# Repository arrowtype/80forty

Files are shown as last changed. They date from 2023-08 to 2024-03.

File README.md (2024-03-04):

# 80forty Keyboard

The utility of an 80% keyboard in a 40% form factor.

Inspired by the design of the [OP-1 Synthesizer](https://teenage.engineering/store/op-1-field/), the explorative spirit of the 40% & 30% keyboard community (especially boards like ChonkyKong, CutiePie, and Ortho Cajal), and the tactile reference points and minimized finger-travel of many split, ergonomic keyboards. The 80forty was partly motivated by the appearance of [Deadline Studio DOYS keycaps](https://deadline.space/products/doys-keycaps), but it works with any MX-compatible keycaps.

The 80forty has a layout that is ortholinear and minimal, but still retains the keys that are helpful for everyday computing and specialized tasks like graphic design applications (i.e. arrow keys, bottom mod keys, and outer columns allowing for e.g. dedicated shift and backspace keys). It also allows either a knob or a 2x2 macropad above the arrow keys.

Supports low-profile KS33 switches (with hotswap sockets) as well as MX switches (soldered/mill-maxed).

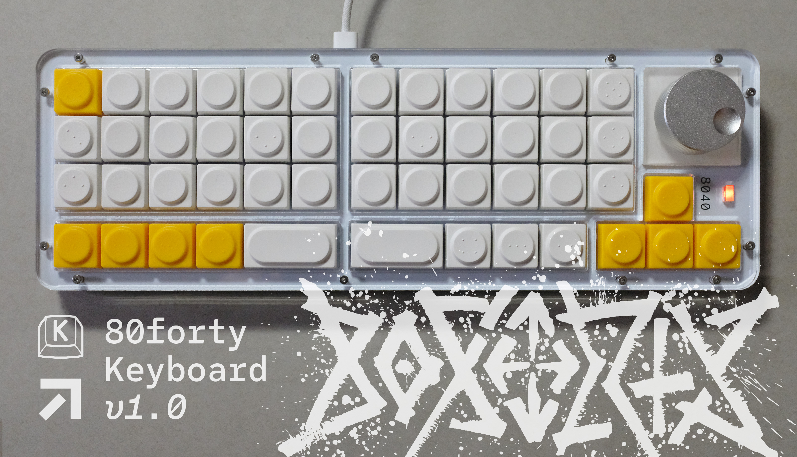
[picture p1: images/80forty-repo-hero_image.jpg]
Overview of 80forty with the v1 stacked acrylic case


## V1 Case Designs

Version 1 uses either a stacked acrylic or ”skeleton” FR4 plate design.

While the PCB supports either KS33 or MX switches, the current case designs have only been settled for the KS33 switches. MX switches require more space, and would likely require larger middle case layers.

### Stacked Acrylic Case

This case uses the standard FR4 top plate of the 80forty, and sandwiches it in a few layers of 5mm, lasercut acrylic.

Side view of 80forty keyboard with stacked acrylic case

Bottom view of 80forty keyboard with stacked acrylic case

### Skeleton FR4 Case

This case uses the standard FR4 top and bottom plates of the 80forty, with standoffs providing middle separation for the switches.

Close-up view of 80forty keyboard with skeleton FR4 case

Profile view of 80forty keyboard with skeleton FR4 case

Close-up bottom view of 80forty keyboard with skeleton FR4 case

## Configuration Options

Configurable with either 1 large knob or 4 macro keys.

80forty-knob

80forty-macro

## Keymaps

80forty is configurable in Vial, so the keymap can be whatever you want! However, here are two example layouts to show what might be common approaches to such a keyboard.

The 2-unit spacebars are intended to serve double duty: to input `Space` when tapped, or to shift to respective layers when held.

80forty-example-keymap-simpler

Vial/QMK also allow for “key combos.” So, for instance, it is possible to forgo a dedicated `Escape` key and instead assign this to `Tilde` + `Q`.

80forty-example-keymap

## Future Vision

The project was conceived to allow a sleek, low-profile, CNC aluminum case design. This is still a goal, but there is no current timeline for this version.

In the slightly nearer term, the intention is to prototype this case with 3D printing. If anyone out there is interested in creating this 3D case and contributing it to the project, let us know in the issues or in a pull request!

8040 Knob

8040 Macro

## Credits

Concept, layout, case design, and PCB graphics by Stephen Nixon / ArrowType.

Engineering, code, and PCB specifications and ordering by Noah Kiser / Kiser Designs.

## To be continued!

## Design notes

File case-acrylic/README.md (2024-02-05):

# 80forty Acrylic Case

TODO: 
- [ ] Sliiightly offset acrylic edges to exceed FR4 plate?
- [ ] Add list of hardware required
  - [ ] Also add this for the skeleton case
- [ ] Document tips for ordering acrylic case

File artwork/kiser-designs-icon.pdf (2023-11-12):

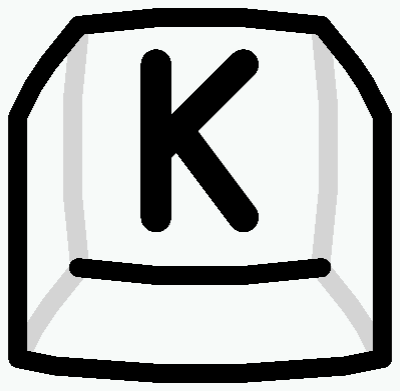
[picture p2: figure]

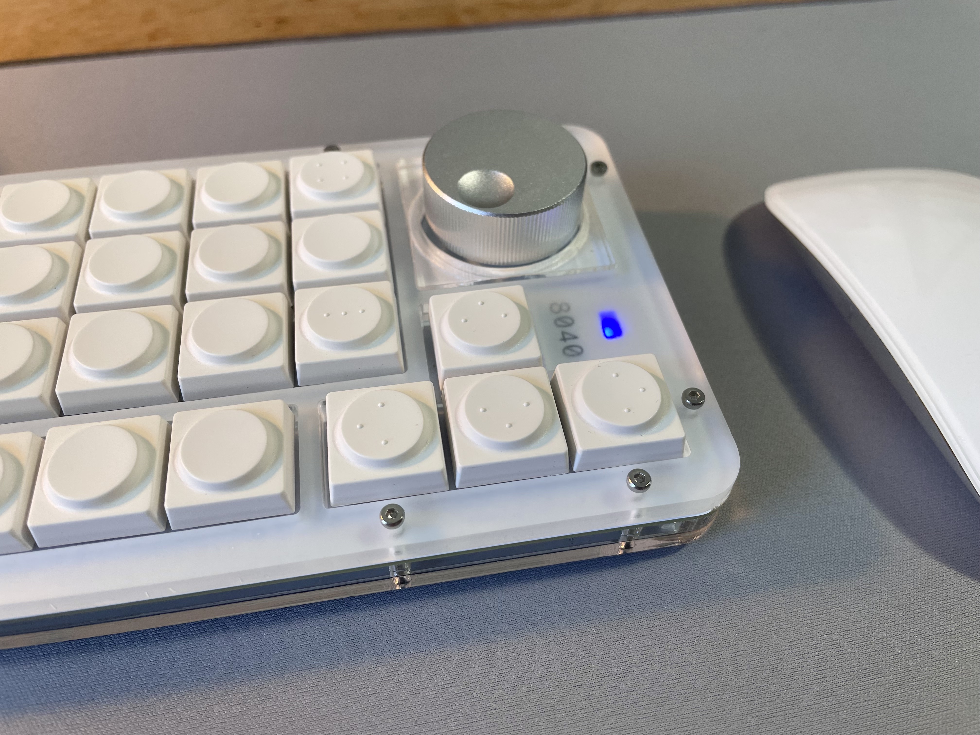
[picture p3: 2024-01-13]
images/80forty-keyboard-v1-detail.jpeg

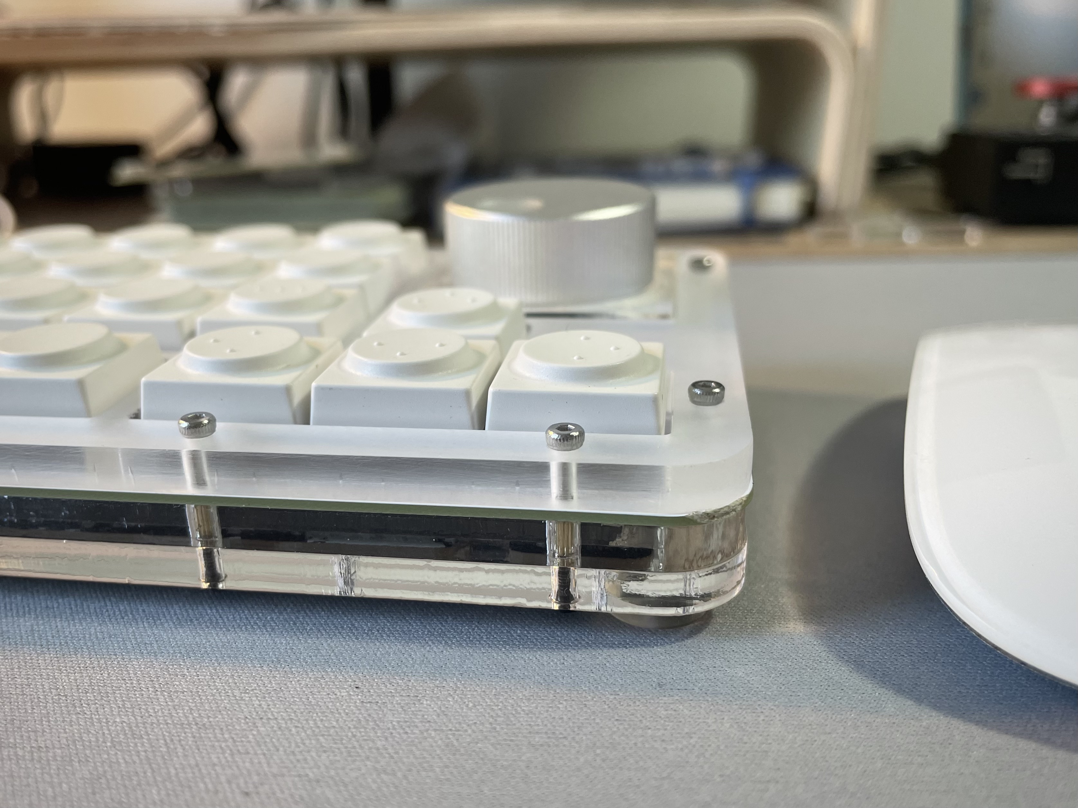
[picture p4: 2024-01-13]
images/80forty-keyboard-v1-side.jpeg

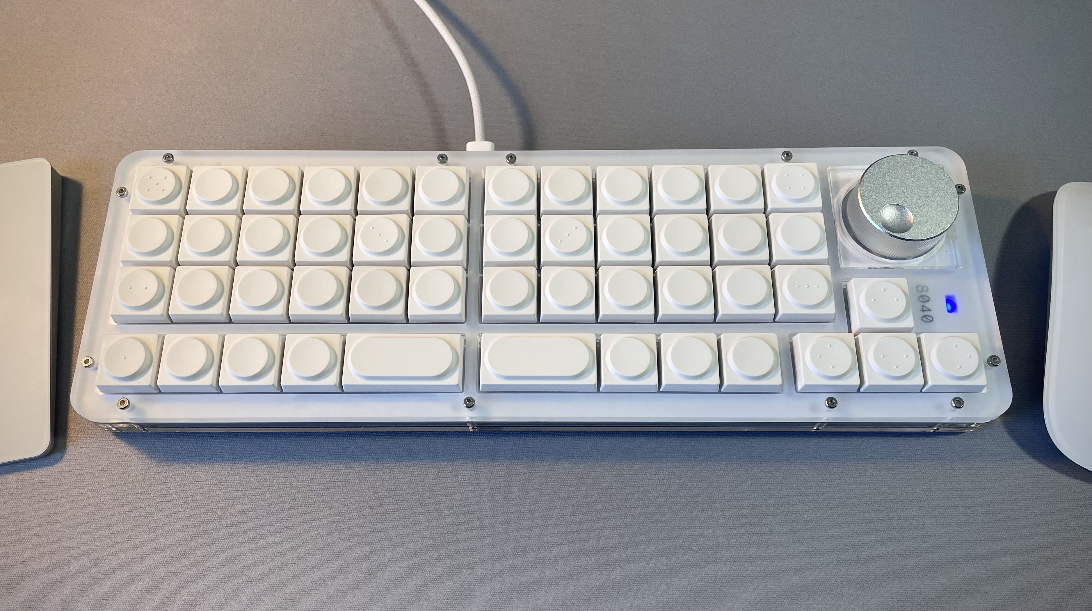
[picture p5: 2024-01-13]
images/80forty-keyboard-v1.jpeg

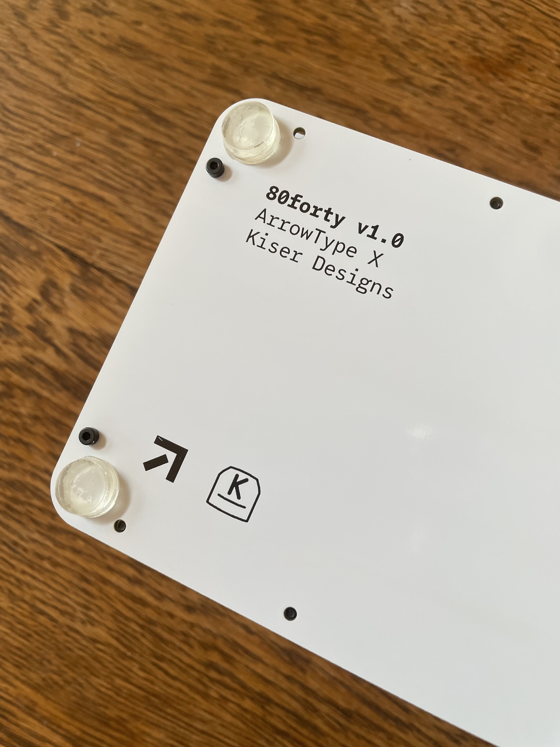
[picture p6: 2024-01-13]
images/80forty-keyboard-v1-skeleton-bottom.jpeg

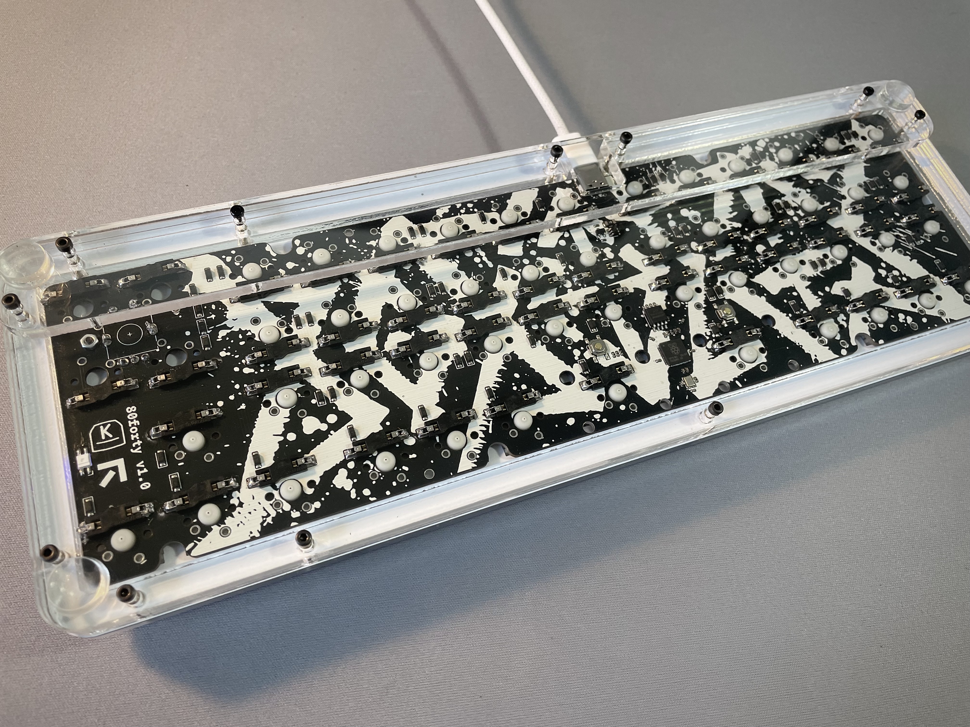
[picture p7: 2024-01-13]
images/80forty-keyboard-v1-bottom.jpeg

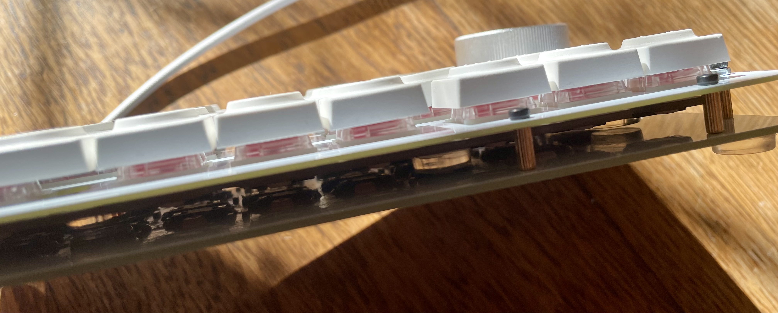
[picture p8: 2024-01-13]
images/80forty-keyboard-v1-skeleton-side.jpeg

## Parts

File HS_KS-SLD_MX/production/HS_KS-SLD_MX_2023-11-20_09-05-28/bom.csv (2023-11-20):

Designator | Footprint | Quantity | Value | LCSC Part #
C1, C2, C4, C5 | 402 | 4 | 1u | C52923
C10, C15, C3, C6, C7, C8, C9 | 402 | 7 | 100n | C1525
C12, C13 | 402 | 2 | 22p | C1562
C14 | 402 | 1 | 10u | C15525
D1, D10, D11, D12, D13, D14, D15, D16, D17, D18, D19, D2, D20, D21, D22, D23, D24, D25, D26, D27, D28, D29, D3, D30, D31, D32, D33, D34, D35, D36, D37, D38, D39, D4, D40, D41, D42, D43, D44, D45, D46, D47, D48, D49, D5, D50, D51, D52, D53, D6, D7, D8, D9 | D_SOD-123 | 53 | D_Small | C81598
F1 | 1206 | 1 | Fuse_Small | C883133
J1 | USB_C_Receptacle_HRO_TYPE-C-31-M-12 | 1 | USB_C_Receptacle_USB2.0 | C165948
LED1 | LED_6028R | 1 | SK6812MINI-E | C5149201
R1, R2, R3, R4, R6 | 402 | 5 | 5.1k | C25905
R5, R9 | 402 | 2 | 1k | C11702
R7, R8 | 402 | 2 | 27 | C25092
SWR1, SWR2 | SW_SPST_TL3342 | 2 | SW_SPST | C318884
U1 | SOT-23 | 1 | XC6206PxxxMR | C5446
U2 | SOT-23-6-routable | 1 | SRV05-4 | C85364
U3 | SOIC-8_5.23x5.23mm_P1.27mm | 1 | W25Q128JVS | C97521
U4 | QFN-56-1EP_7x7mm_P0.4mm_EP3.2x3.2mm | 1 | RP2040TR7 | C2040
Y1 | Crystal_SMD_3225-4Pin_3.2x2.5mm | 1 | Crystal_GND24_Small | C9002
 |  |  |  |  | s

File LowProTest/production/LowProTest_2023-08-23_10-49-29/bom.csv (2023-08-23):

Designator | Footprint | Quantity | Value | LCSC Part #
SW1_2, SW1 | gateron-ks-33 | 2 | SW_Push_45deg
SW2_2, SW2 | KS-33-HS | 2 | SW_Push_45deg
SW8_2, SW8 | SW_MX_HS_1u | 2 | SW_Push_45deg

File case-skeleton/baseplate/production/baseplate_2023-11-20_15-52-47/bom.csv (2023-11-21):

Designator | Footprint | Quantity | Value | LCSC Part #
_13, _12, _11, _10, _9, _8, _7, _6, _5, _4, _3, _2, |  | 13

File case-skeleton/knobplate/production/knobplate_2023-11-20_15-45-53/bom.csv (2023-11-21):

Designator | Footprint | Quantity | Value | LCSC Part #
_18, _17, _16, _15, _14, _13, _12, _11, _10, _9, _8, _7, _6, _5, _4, _3, _2, |  | 18

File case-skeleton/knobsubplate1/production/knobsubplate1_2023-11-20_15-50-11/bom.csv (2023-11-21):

Designator | Footprint | Quantity | Value | LCSC Part #
_4, _3, _2, |  | 4

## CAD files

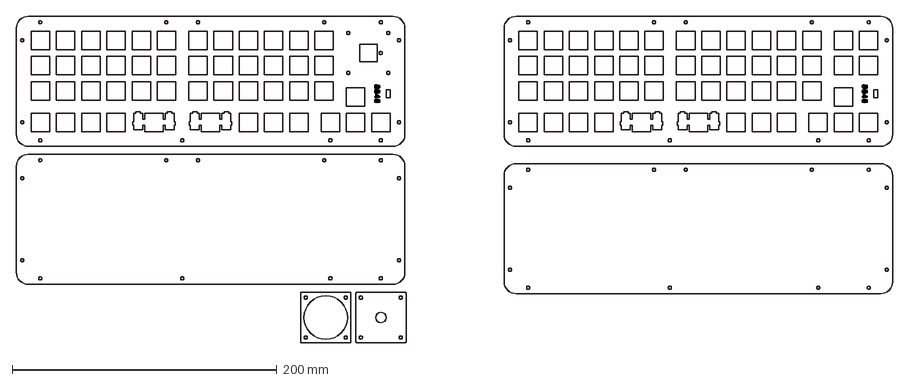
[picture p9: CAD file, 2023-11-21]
case-skeleton/80forty-plates_to_cut-2023_11_20.dxf
661.8 x 246.6 mm

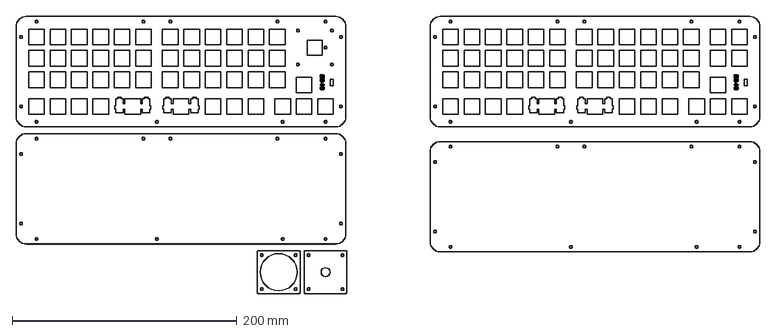
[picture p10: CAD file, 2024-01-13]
plates/80forty-plates_to_cut-2023_11_20.dxf
661.8 x 246.6 mm

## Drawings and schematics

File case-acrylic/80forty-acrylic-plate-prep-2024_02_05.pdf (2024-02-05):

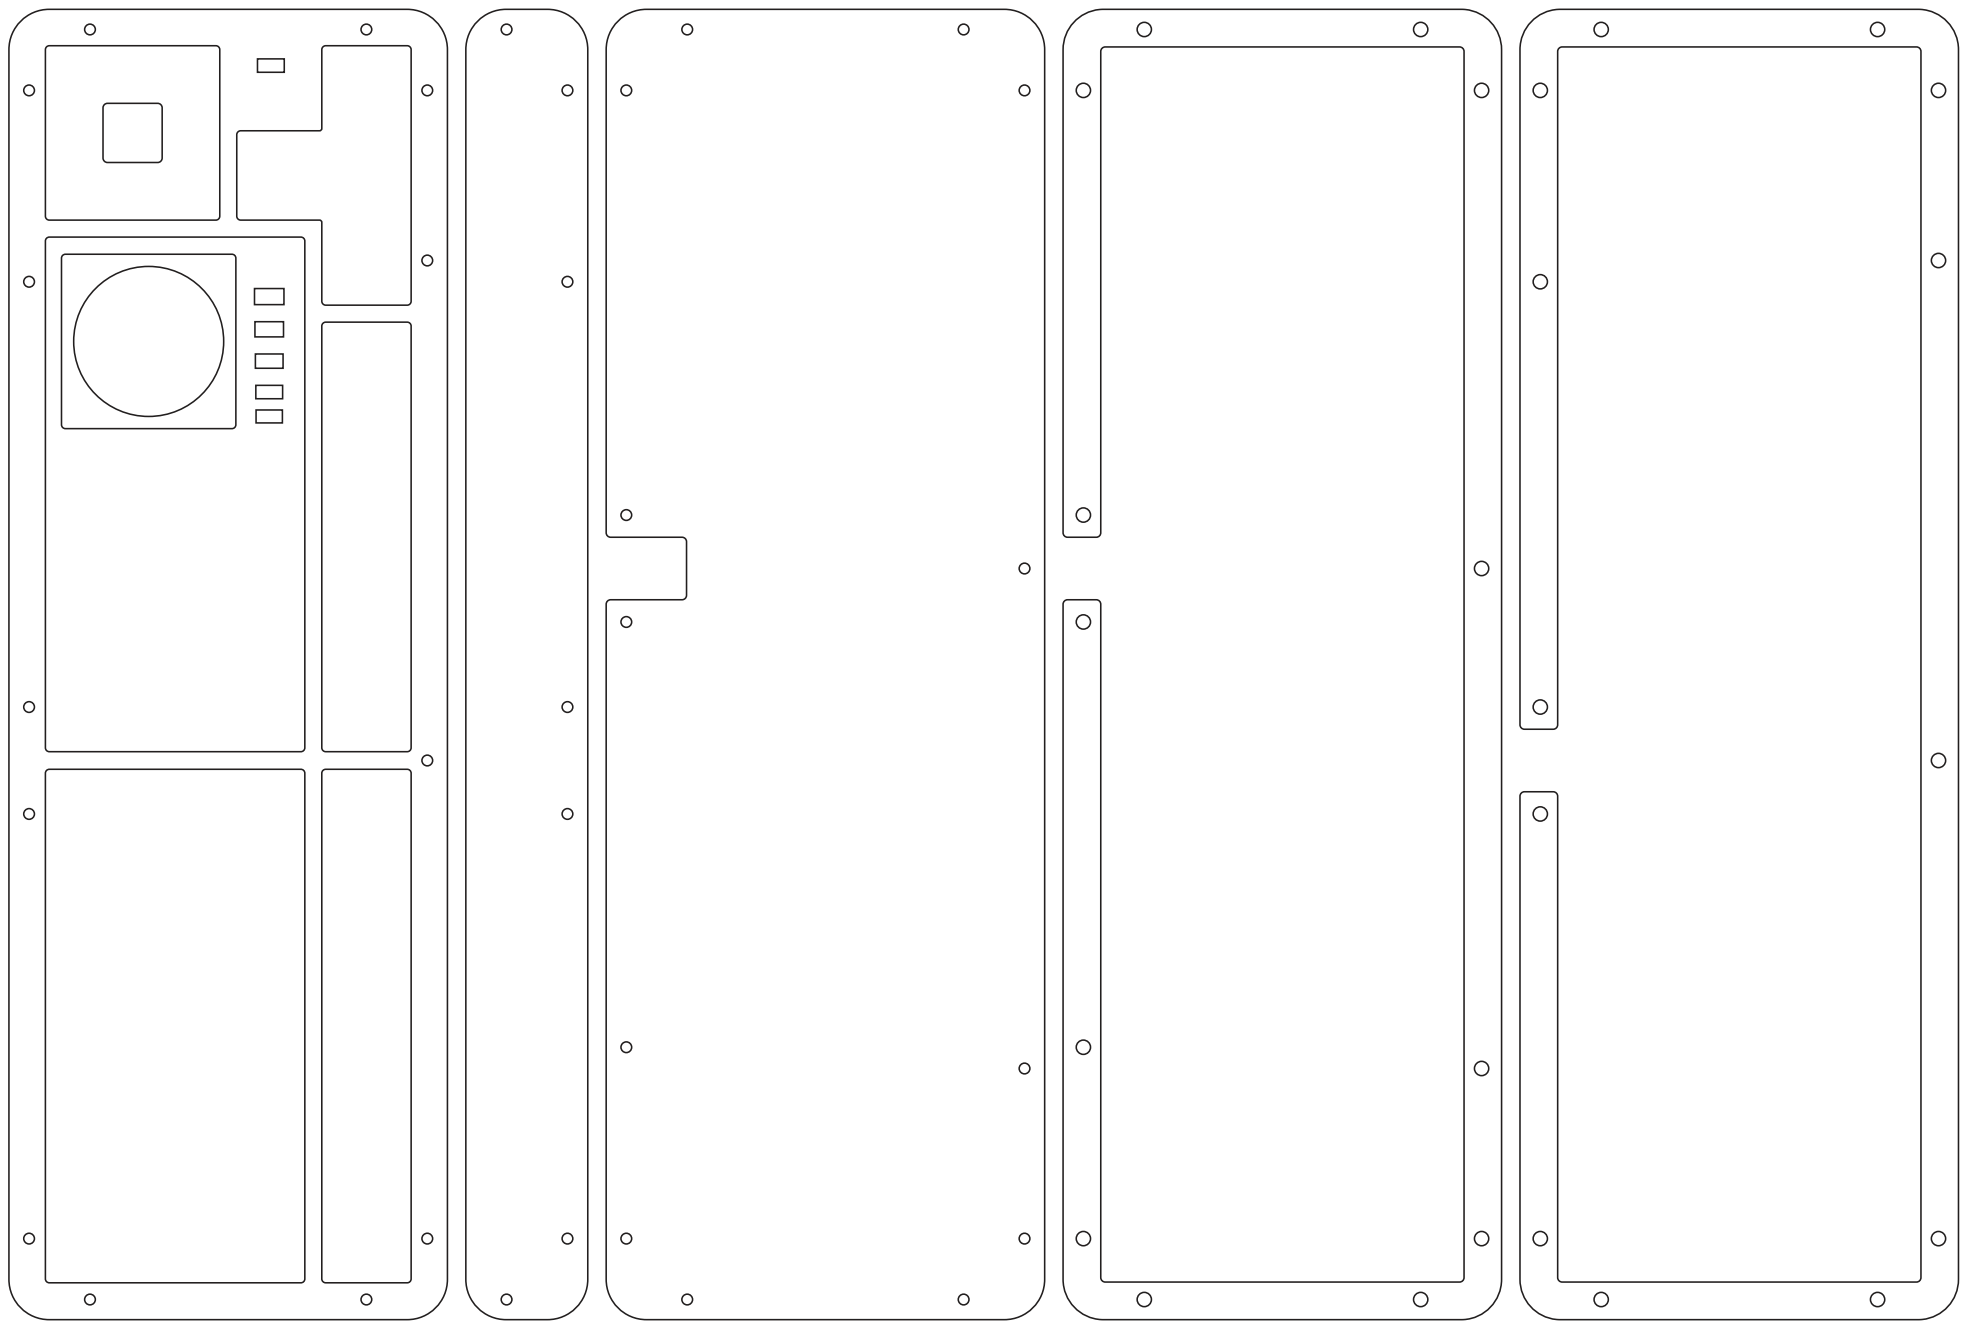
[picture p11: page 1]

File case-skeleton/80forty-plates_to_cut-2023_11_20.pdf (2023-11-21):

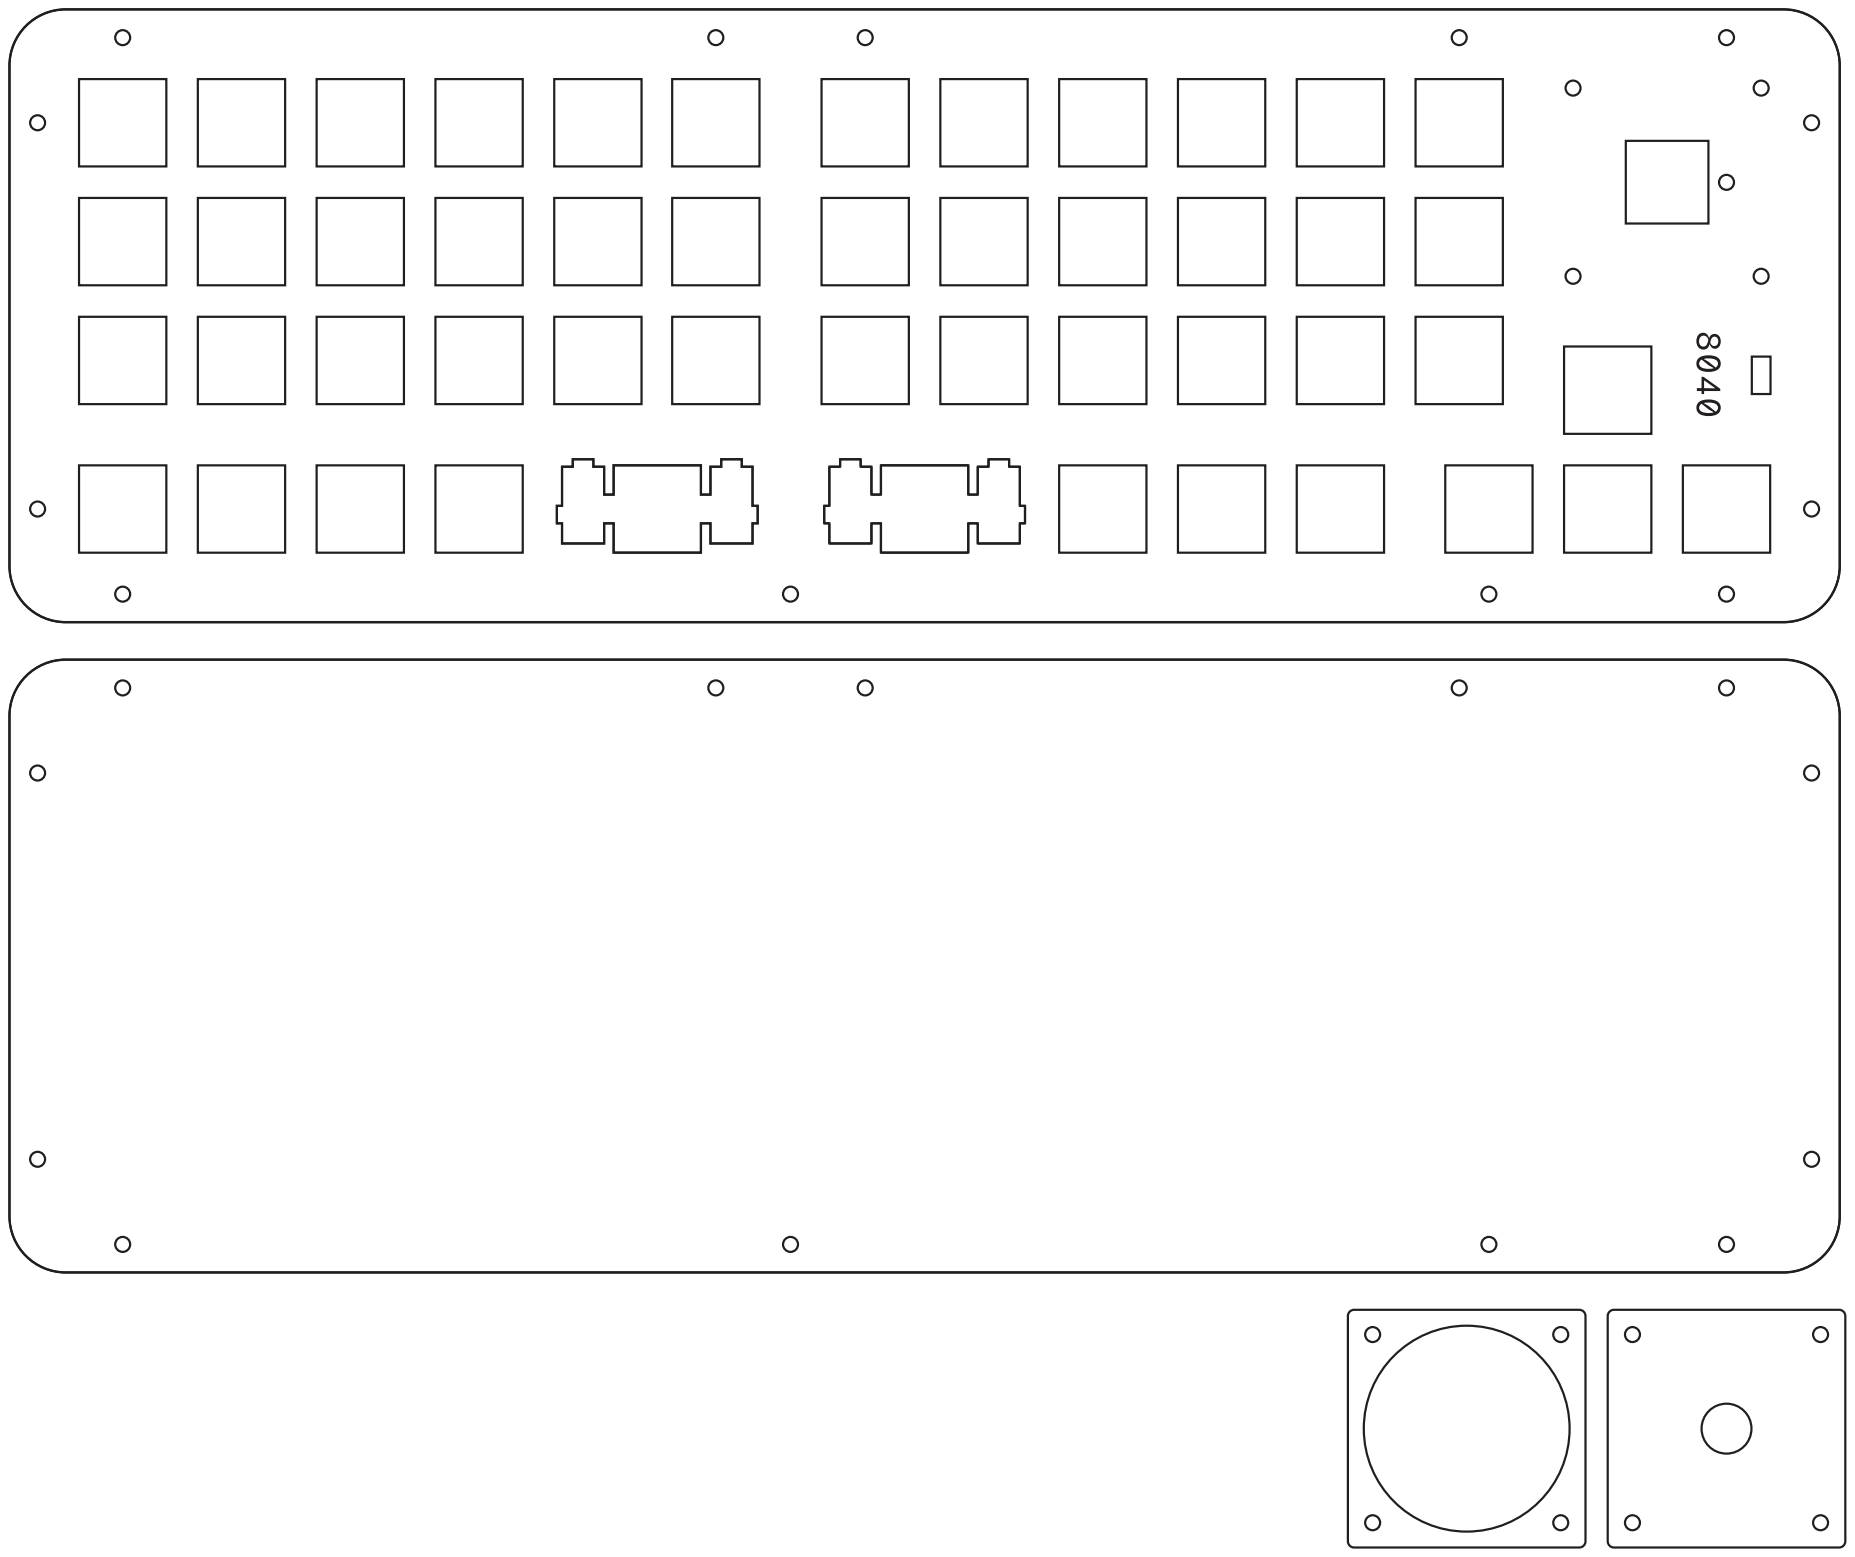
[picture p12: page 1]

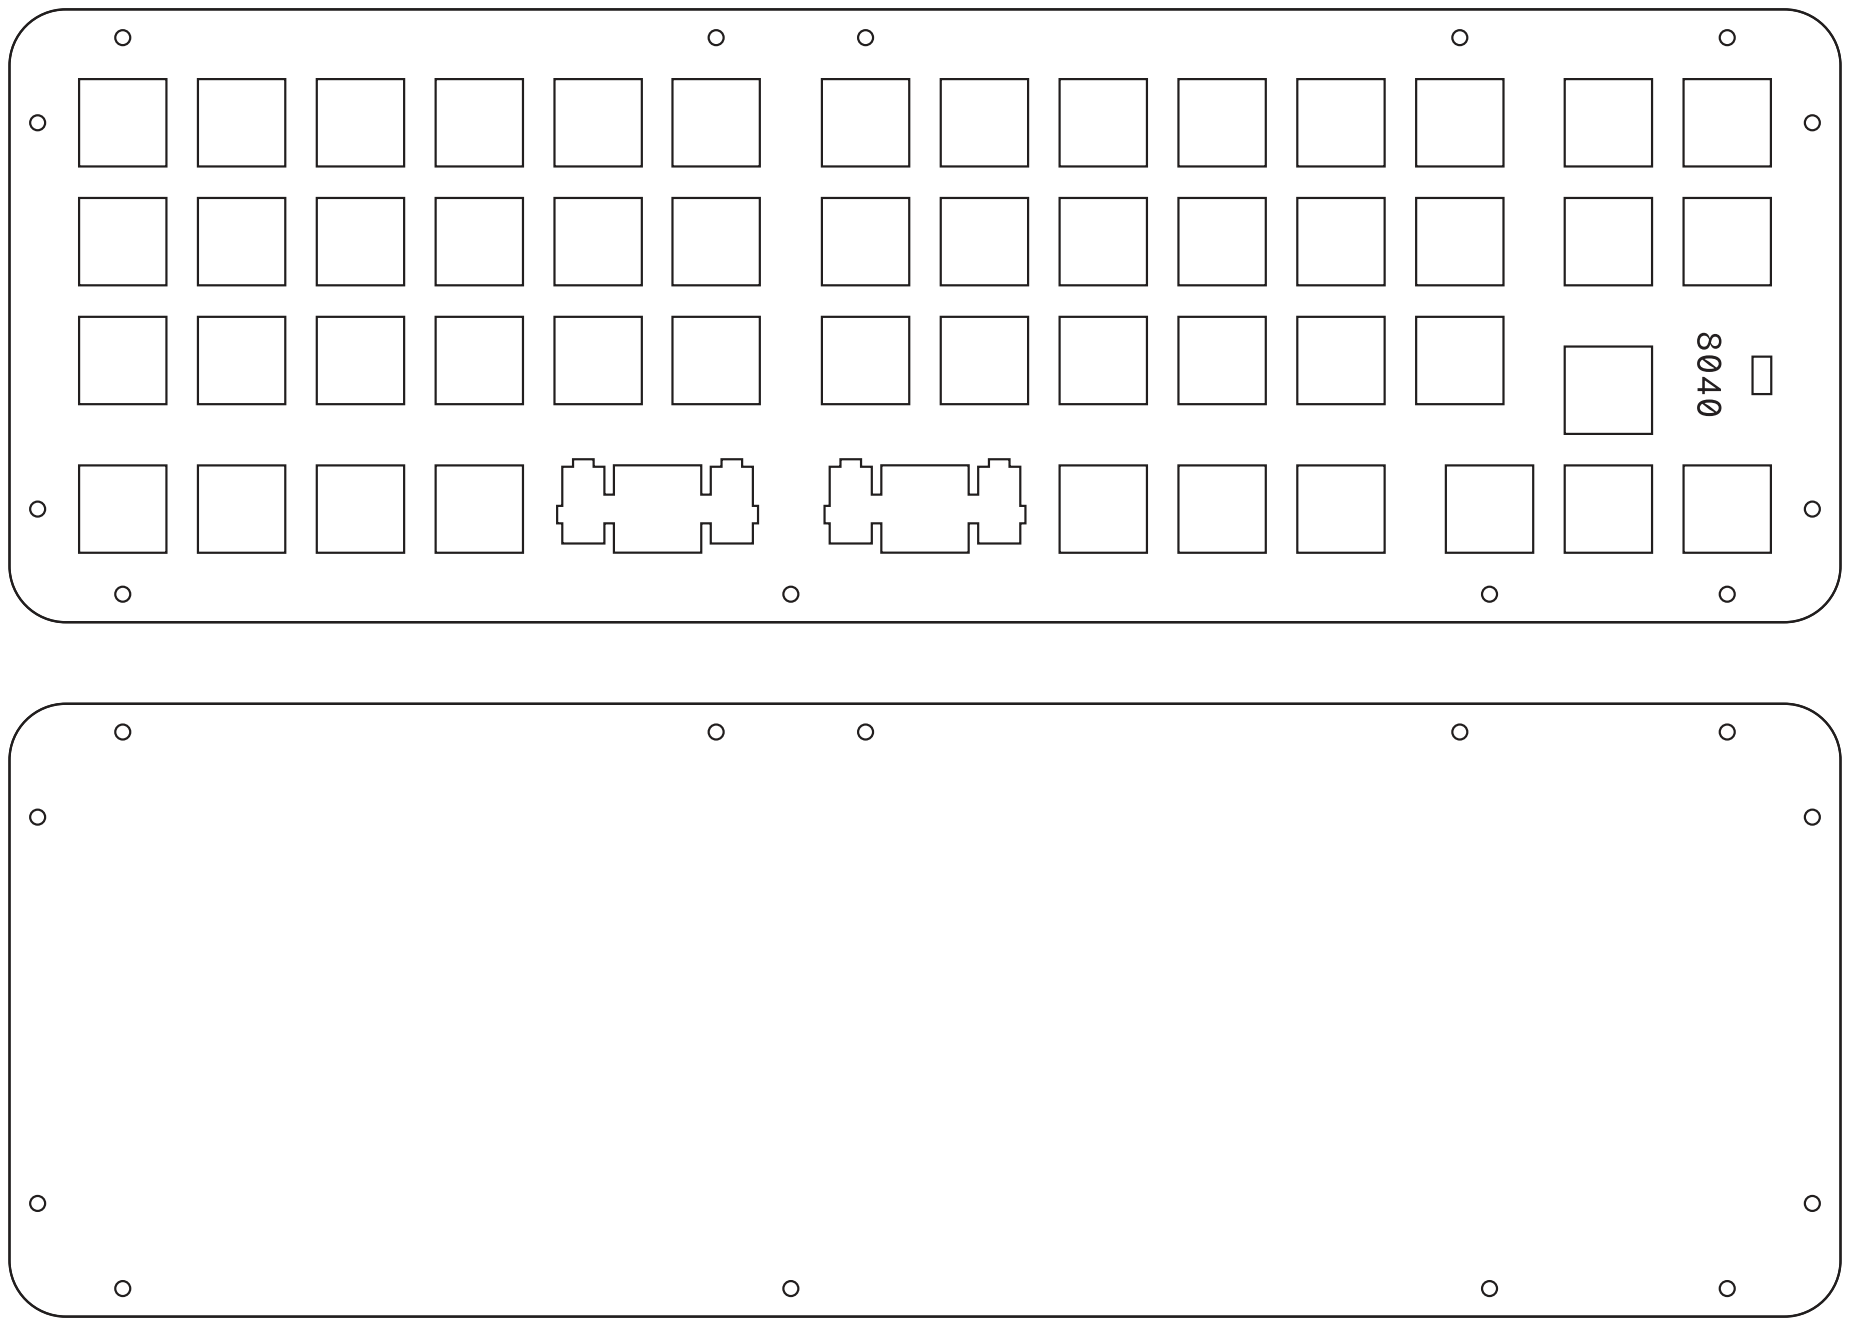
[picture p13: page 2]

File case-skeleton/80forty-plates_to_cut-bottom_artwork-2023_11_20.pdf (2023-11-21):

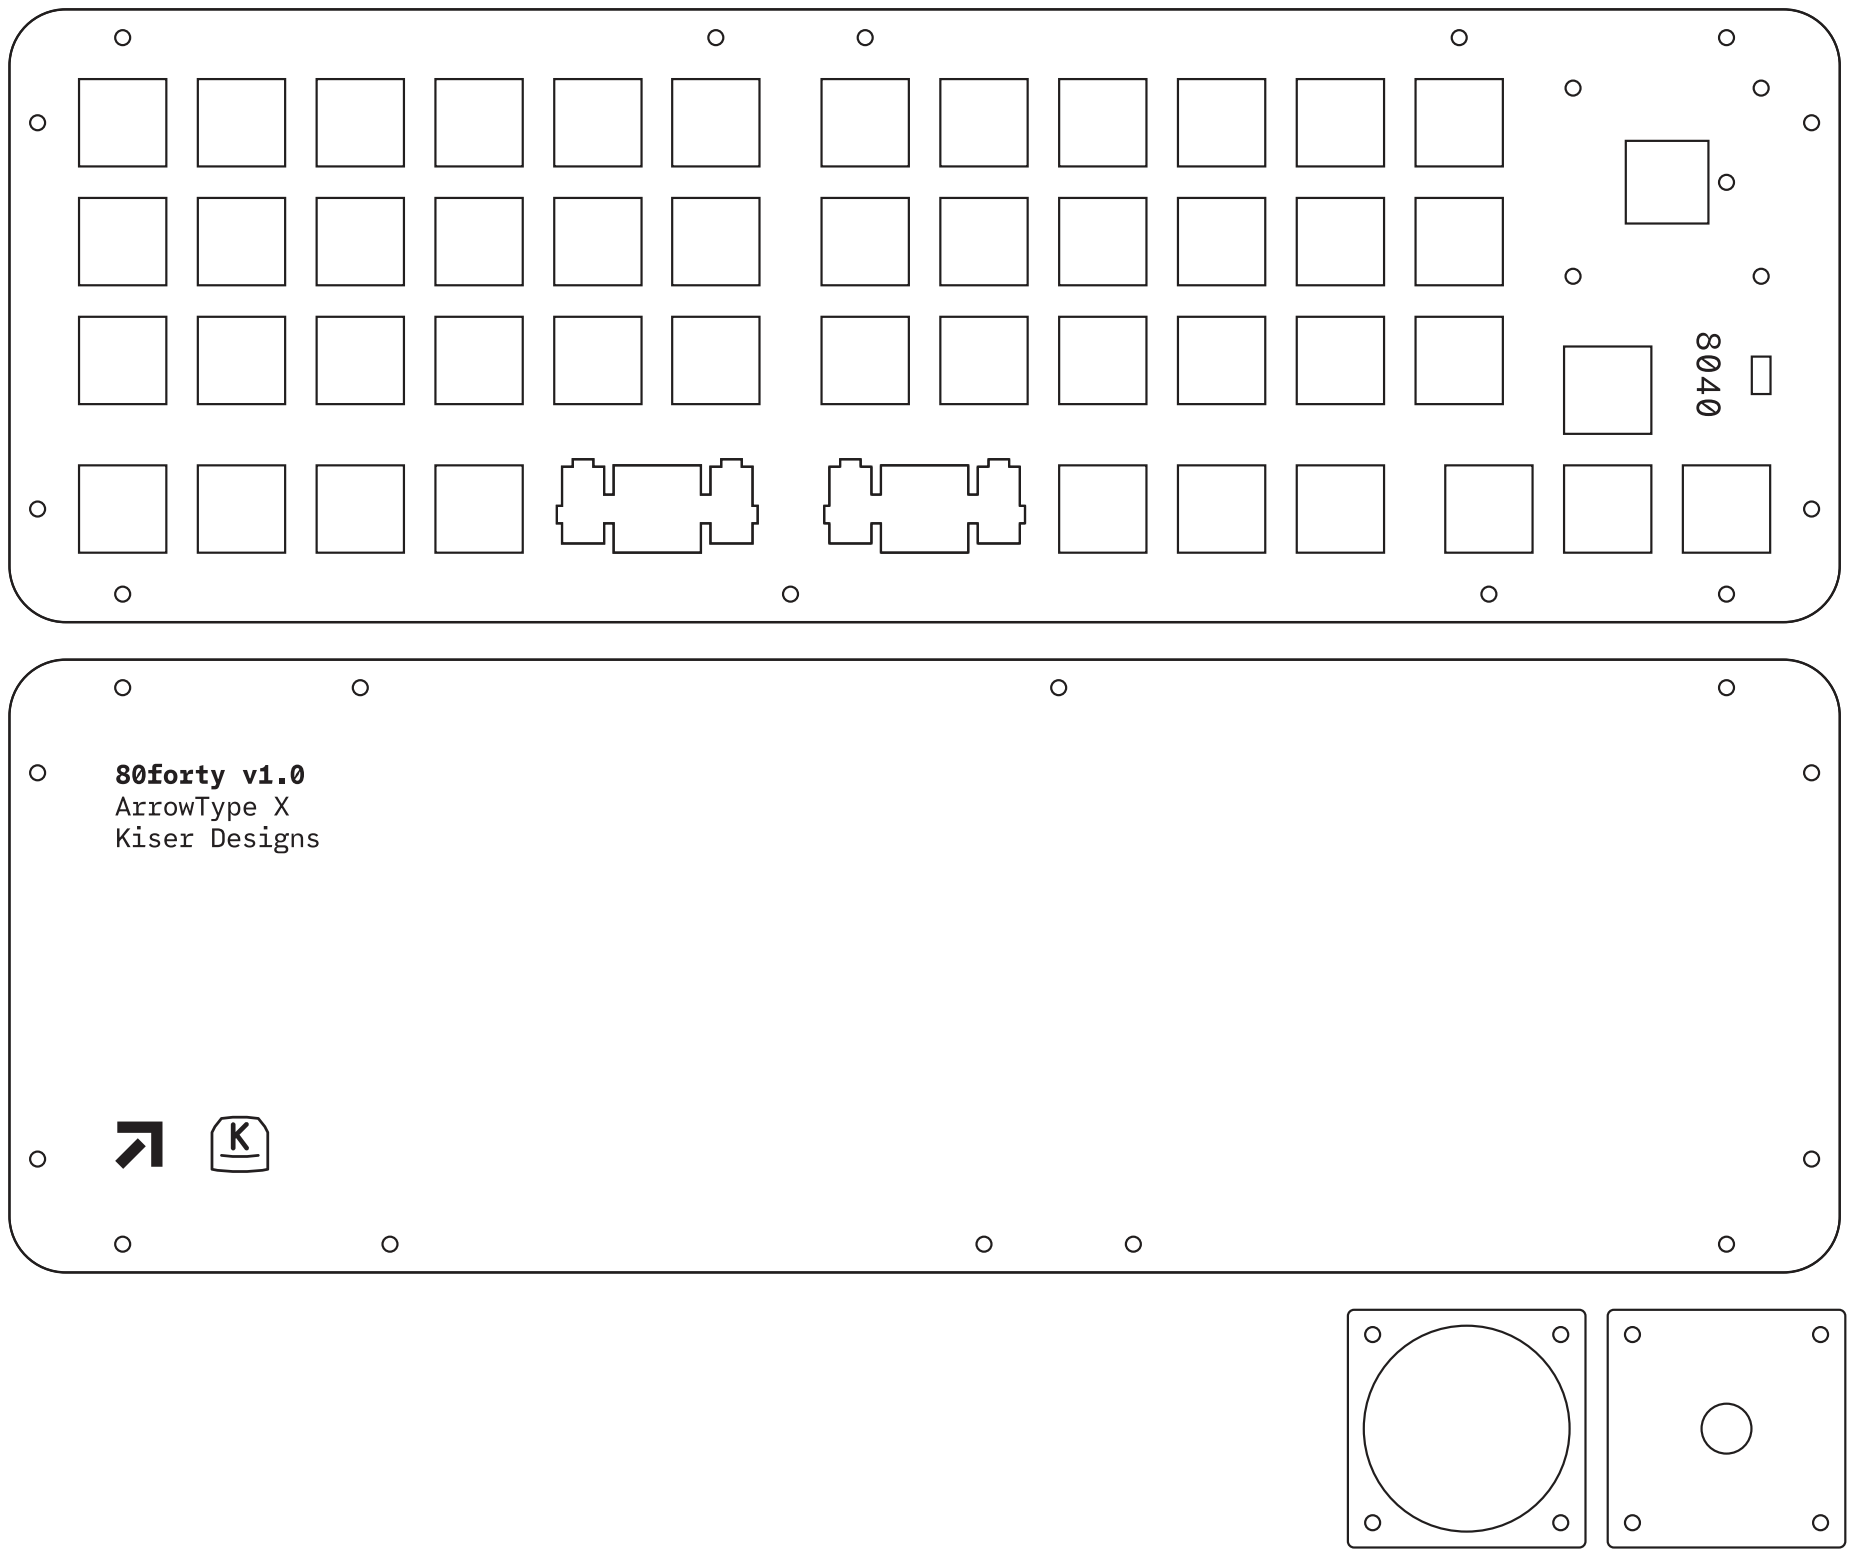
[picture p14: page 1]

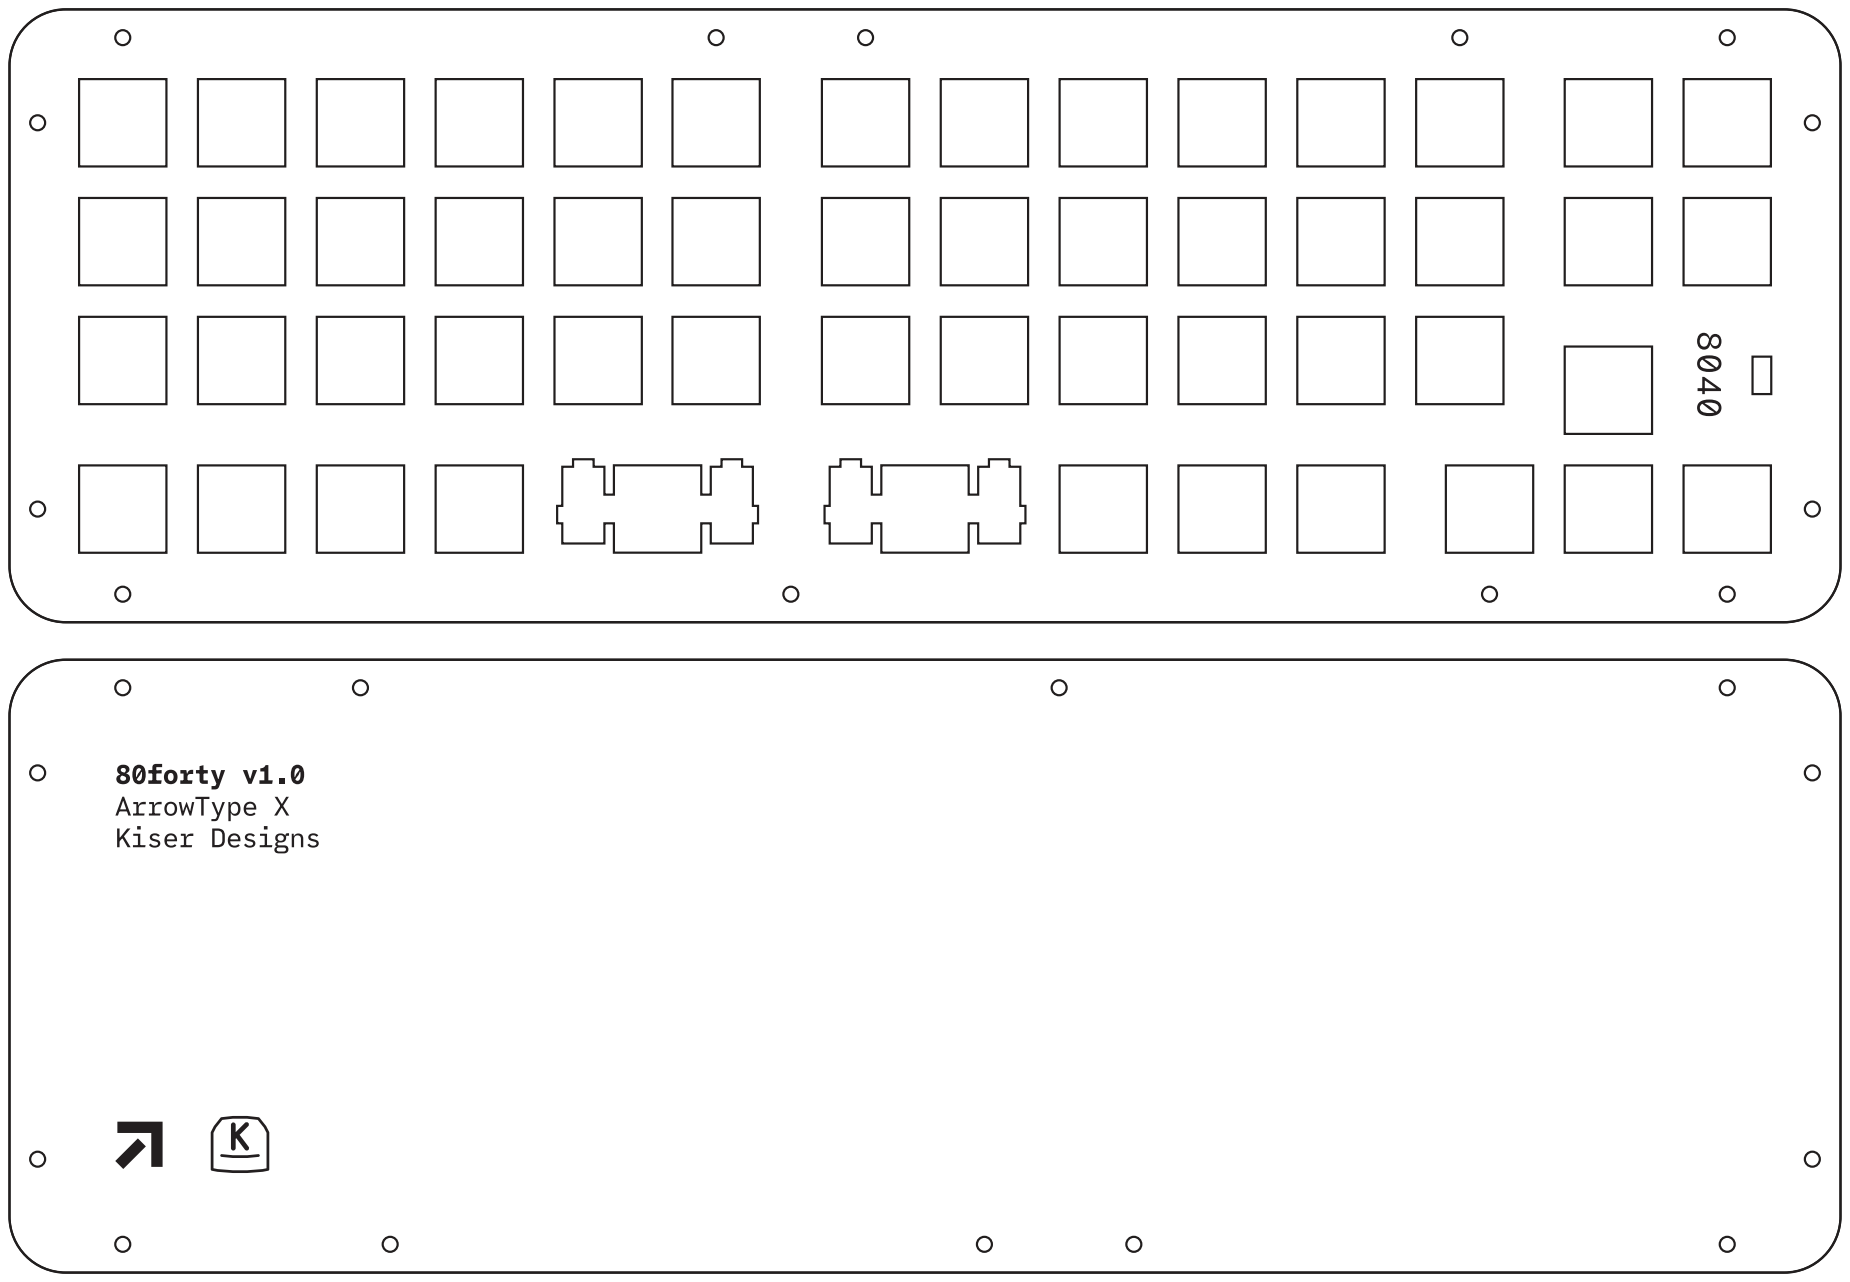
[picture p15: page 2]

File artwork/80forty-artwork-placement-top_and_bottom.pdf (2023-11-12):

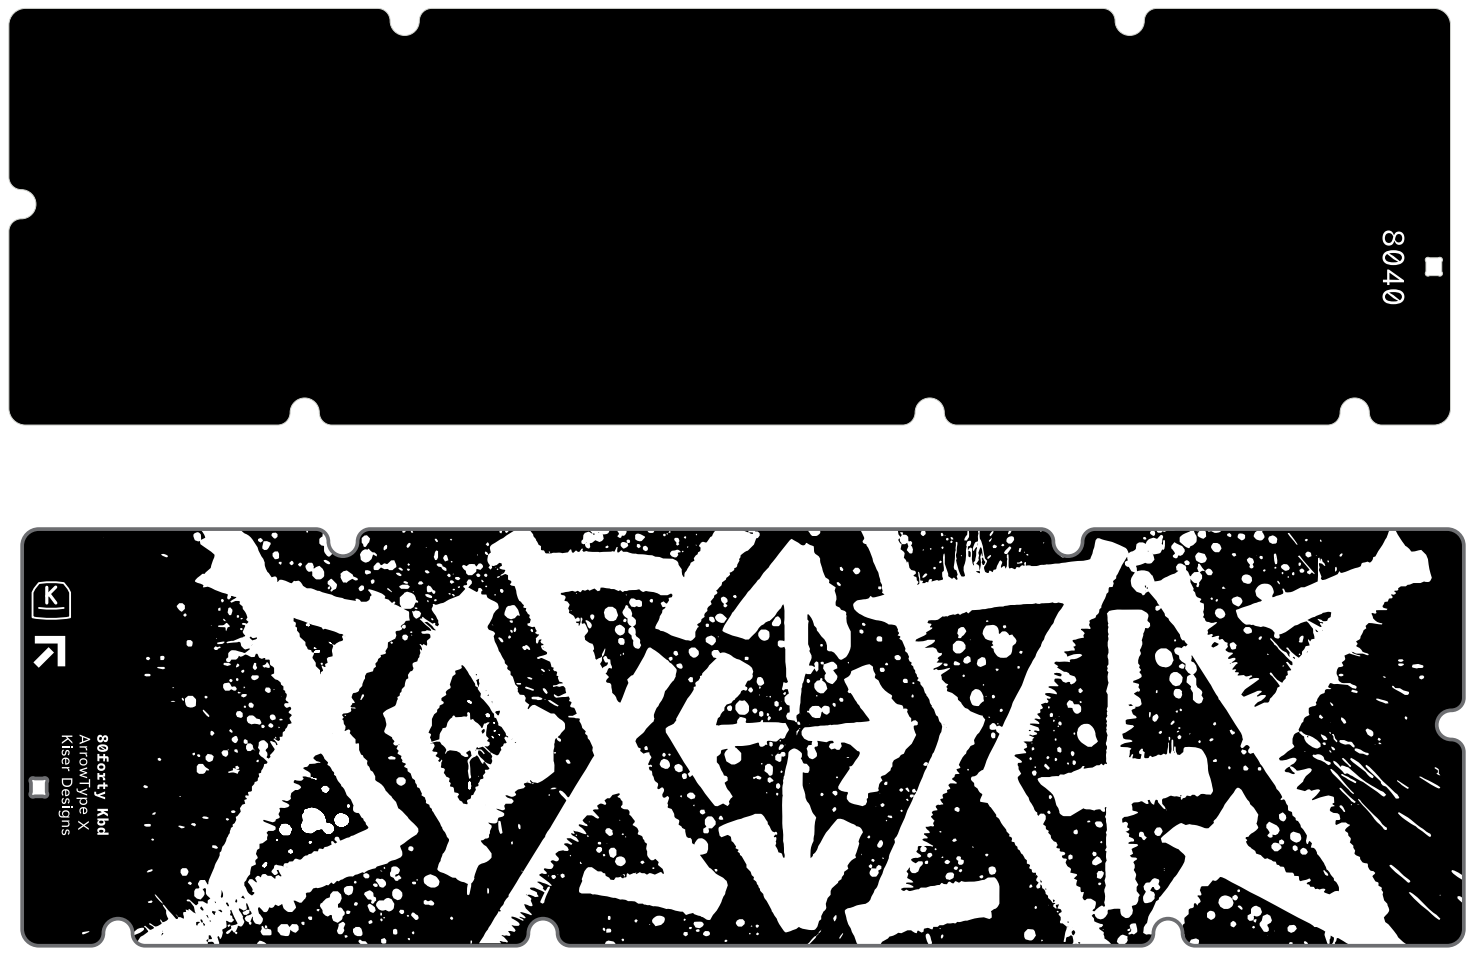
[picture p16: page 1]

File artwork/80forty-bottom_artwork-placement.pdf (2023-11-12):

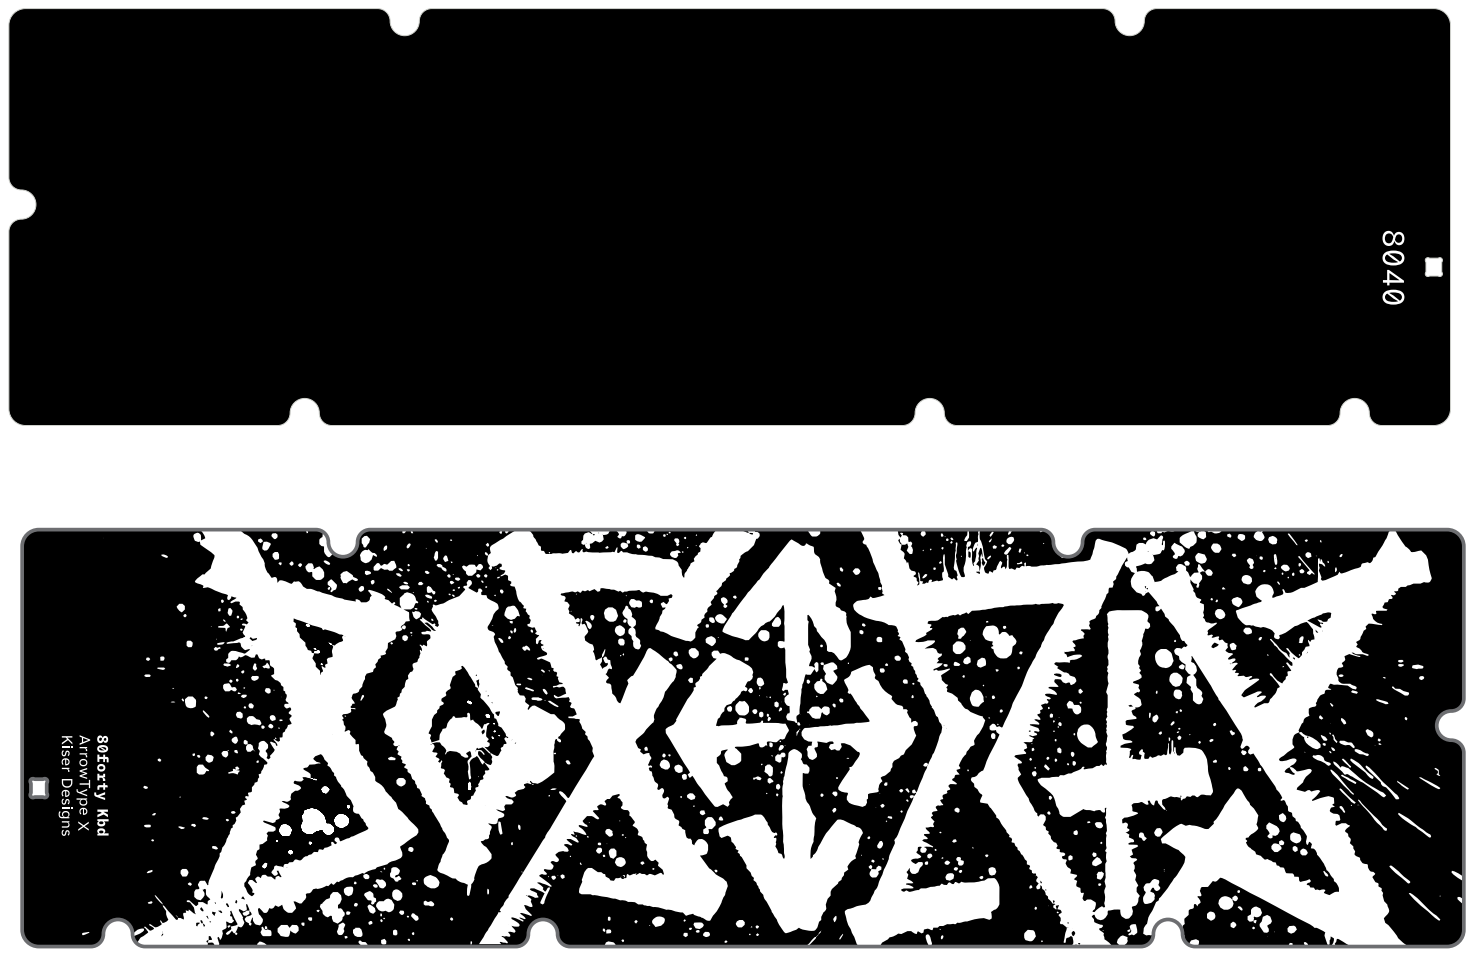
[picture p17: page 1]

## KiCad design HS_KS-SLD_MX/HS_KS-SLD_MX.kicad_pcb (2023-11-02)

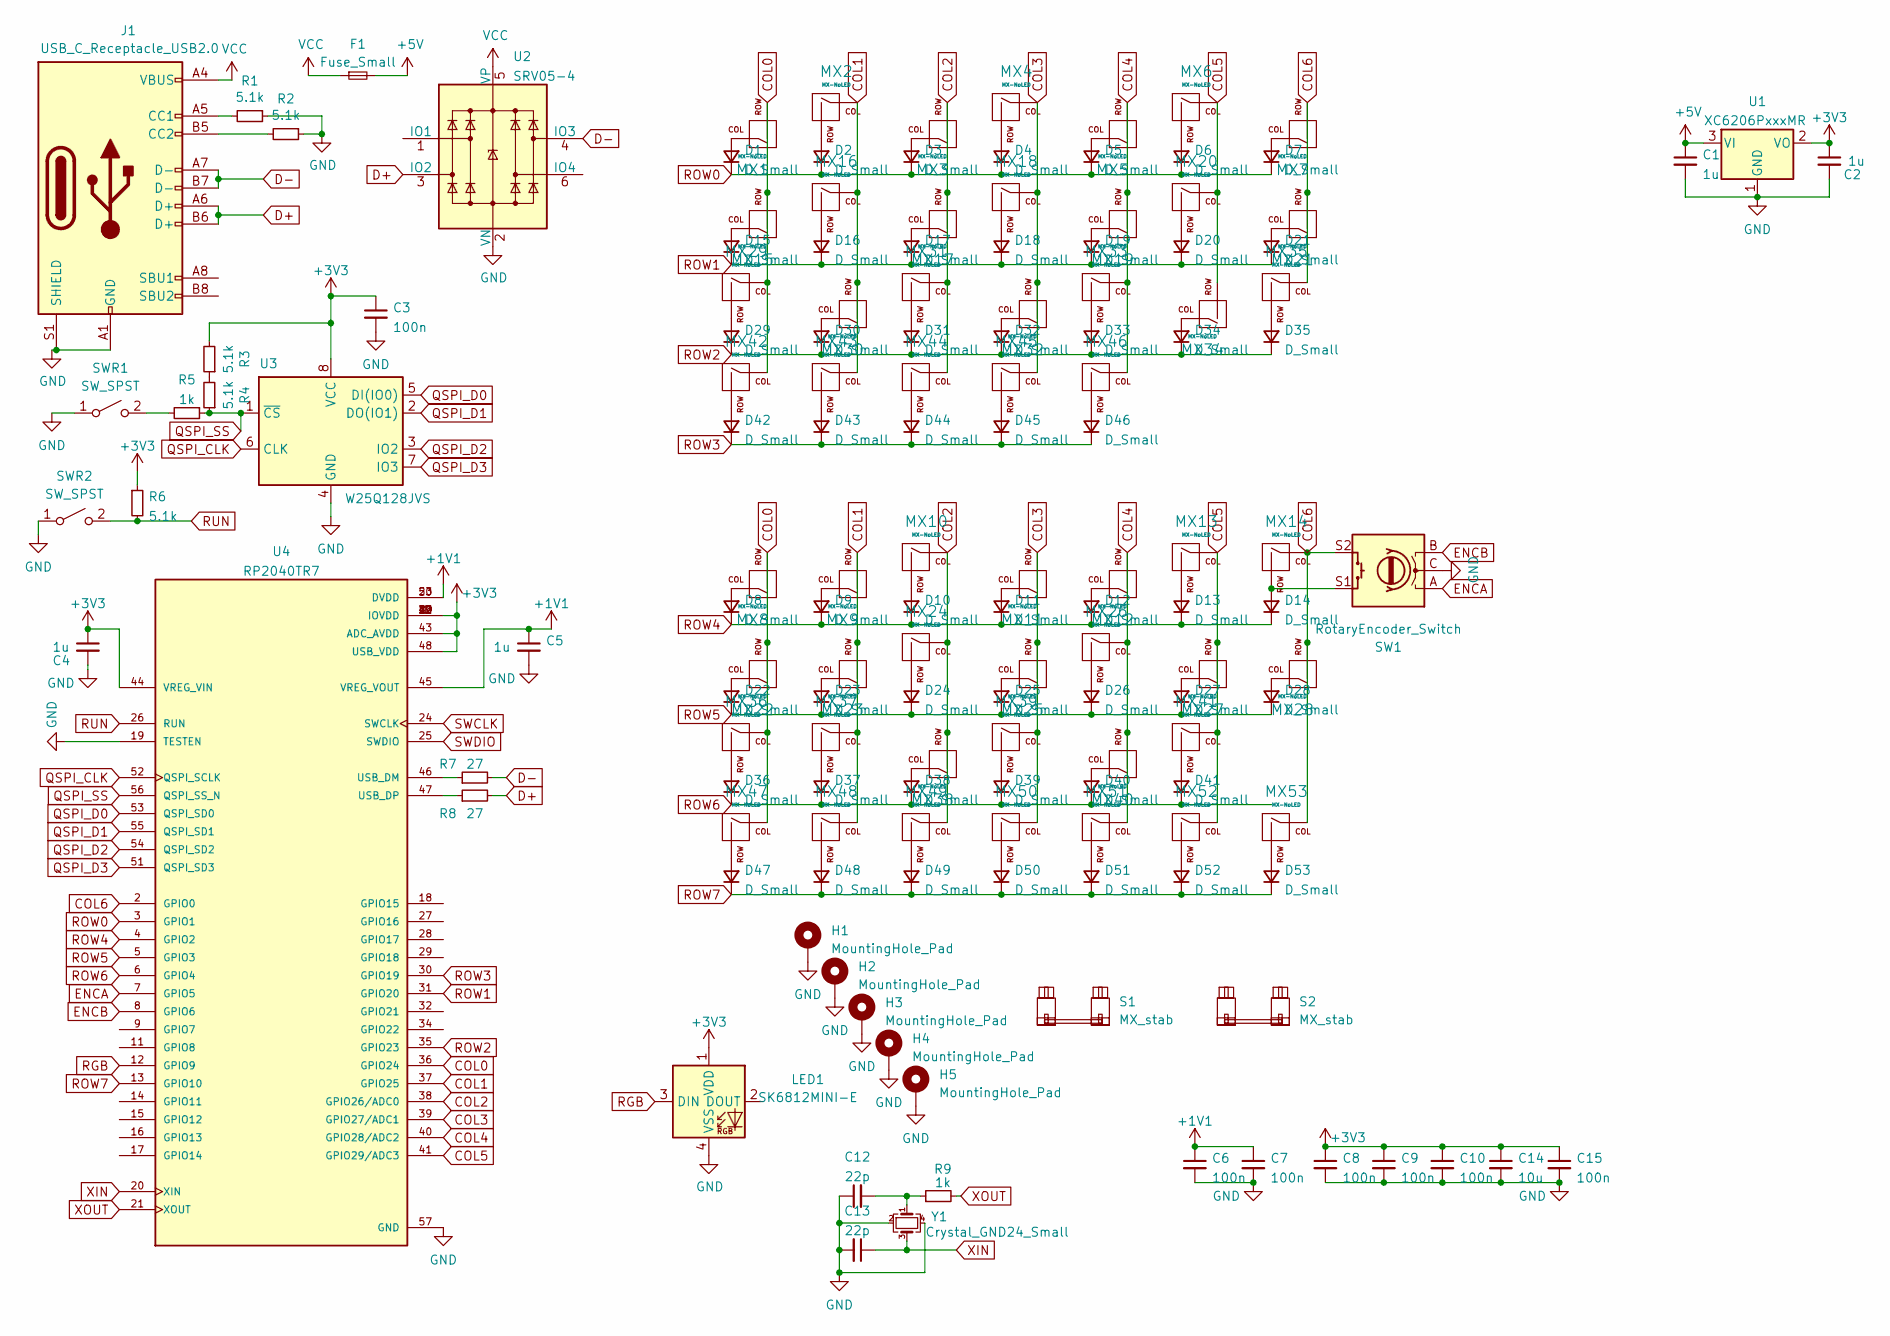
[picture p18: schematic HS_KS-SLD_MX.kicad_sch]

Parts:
C1, C2, C4, C5: 1u; C_0402_1005Metric
C3, C6, C7, C8, C9, C10, C15: 100n; C_0402_1005Metric
C12, C13: 22p; C_0402_1005Metric
C14: 10u; C_0402_1005Metric
D1, D2, D3, D4, D5, D6, D7, D8, D9, D10, D11, D12, D13, D14, D15, D16, D17, D18, D19, D20, D21, D22, D23, D24, D25, D26, D27, D28, D29, D30, D31, D32, D33, D34, D35, D36, D37, D38, D39, D40, D41, D42, D43, D44, D45, D46, D47, D48, D49, D50, D51, D52, D53: D_Small; D_SOD-123
F1: Fuse_Small; Fuse_1206_3216Metric
H1, H2, H3, H4, H5: MountingHole_Pad; MountingHole_2.2mm_M2_Pad_TopOnly
J1: USB_C_Receptacle_USB2.0; USB_C_Receptacle_HRO_TYPE-C-31-M-12
LED1: SK6812MINI-E; LED_6028R
MX1, MX2, MX3, MX4, MX5, MX6, MX7, MX8, MX9, MX10, MX11, MX12, MX13, MX14, MX15, MX16, MX17, MX18, MX19, MX20, MX21, MX22, MX23, MX24, MX25, MX26, MX27, MX28, MX29, MX30, MX31, MX32, MX33, MX34, MX35, MX36, MX37, MX38, MX39, MX40, MX41, MX42, MX43, MX44, MX45, MX46, MX47, MX48, MX49, MX50, MX51, MX52, MX53: MX-NoLED; HS-KS-33_Soldered-MX
R1, R2, R3, R4, R6: 5.1k; R_0402_1005Metric
R5, R9: 1k; R_0402_1005Metric
R7, R8: 27; R_0402_1005Metric
S1, S2: MX_stab; STAB_MX_P_2u
SW1: RotaryEncoder_Switch; RotaryEncoder_Alps_EC11E-Switch_Vertical_H20mm
SWR1, SWR2: SW_SPST; SW_SPST_TL3342
U1: XC6206PxxxMR; SOT-23
U2: SRV05-4; SOT-23-6-routable
U3: W25Q128JVS; SOIC-8_5.23x5.23mm_P1.27mm
U4: RP2040TR7; QFN-56-1EP_7x7mm_P0.4mm_EP3.2x3.2mm; PARTREV 1.7.1
Y1: Crystal_GND24_Small; Crystal_SMD_3225-4Pin_3.2x2.5mm

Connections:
+1V1: C5.1, C6.1, C7.1, U4.23 (DVDD), U4.45 (VREG_VOUT), U4.50 (DVDD)
+3V3: C2.1, C3.1, C4.1, C8.1, C9.1, C10.1, C14.1, C15.1, LED1.1 (VDD), R3.2, R6.1, U1.2 (VO), U3.8 (VCC), U4.1 (IOVDD), U4.10 (IOVDD), U4.22 (IOVDD), U4.33 (IOVDD), U4.42 (IOVDD), U4.43 (ADC_AVDD), U4.44 (VREG_VIN), U4.48 (USB_VDD), U4.49 (IOVDD)
+5V: C1.1, F1.2, U1.3 (VI)
COL0: MX1.2 (ROW), MX8.2 (ROW), MX15.2 (ROW), MX22.2 (ROW), MX29.1 (COL), MX36.1 (COL), MX42.1 (COL), MX47.1 (COL), U4.36 (GPIO24)
COL1: MX2.1 (COL), MX9.2 (ROW), MX16.1 (COL), MX23.2 (ROW), MX30.2 (ROW), MX37.1 (COL), MX43.1 (COL), MX48.1 (COL), U4.37 (GPIO25)
COL2: MX3.2 (ROW), MX10.1 (COL), MX17.2 (ROW), MX24.1 (COL), MX31.1 (COL), MX38.2 (ROW), MX44.1 (COL), MX49.1 (COL), U4.38 (GPIO26/ADC0)
COL3: MX4.1 (COL), MX11.2 (ROW), MX18.1 (COL), MX25.2 (ROW), MX32.2 (ROW), MX39.1 (COL), MX45.1 (COL), MX50.1 (COL), U4.39 (GPIO27/ADC1)
COL4: MX5.2 (ROW), MX12.2 (ROW), MX19.2 (ROW), MX26.1 (COL), MX33.1 (COL), MX40.2 (ROW), MX46.1 (COL), MX51.1 (COL), U4.40 (GPIO28/ADC2)
COL5: MX6.1 (COL), MX13.1 (COL), MX20.1 (COL), MX27.2 (ROW), MX34.2 (ROW), MX41.1 (COL), MX52.1 (COL), U4.41 (GPIO29/ADC3)
COL6: MX7.2 (ROW), MX14.1 (COL), MX21.2 (ROW), MX28.2 (ROW), MX35.1 (COL), MX53.1 (COL), SW1.S2, U4.2 (GPIO0)
D+: J1.A6 (D+), J1.B6 (D+), R8.2, U2.3 (IO2)
D-: J1.A7 (D-), J1.B7 (D-), R7.2, U2.4 (IO3)
ENCA: SW1.A, U4.7 (GPIO5)
ENCB: SW1.B, U4.8 (GPIO6)
GND: C1.2, C2.2, C3.2, C4.2, C5.2, C6.2, C7.2, C8.2, C9.2, C10.2, C12.1, C13.2, C14.2, C15.2, H1.1, H2.1, H3.1, H4.1, H5.1, J1.A1 (GND), J1.A12 (GND), J1.B1 (GND), J1.B12 (GND), J1.S1 (SHIELD), LED1.4 (VSS), R1.1, R2.1, SW1.C, SWR1.1 (A), SWR2.1 (A), U1.1 (GND), U2.2 (VN), U3.4 (GND), U4.19 (TESTEN), U4.57 (GND), Y1.2, Y1.4
unnamed: C12.2, R9.1, Y1.1
unnamed: D1.2 (A), MX1.1 (COL)
unnamed: D2.2 (A), MX2.2 (ROW)
unnamed: D3.2 (A), MX3.1 (COL)
unnamed: D4.2 (A), MX4.2 (ROW)
unnamed: D5.2 (A), MX5.1 (COL)
unnamed: D6.2 (A), MX6.2 (ROW)
unnamed: D7.2 (A), MX7.1 (COL)
unnamed: D8.2 (A), MX8.1 (COL)
unnamed: D9.2 (A), MX9.1 (COL)
unnamed: D10.2 (A), MX10.2 (ROW)
unnamed: D11.2 (A), MX11.1 (COL)
unnamed: D12.2 (A), MX12.1 (COL)
unnamed: D13.2 (A), MX13.2 (ROW)
unnamed: D14.2 (A), MX14.2 (ROW), SW1.S1
unnamed: D15.2 (A), MX15.1 (COL)
unnamed: D16.2 (A), MX16.2 (ROW)
unnamed: D17.2 (A), MX17.1 (COL)
unnamed: D18.2 (A), MX18.2 (ROW)
unnamed: D19.2 (A), MX19.1 (COL)
unnamed: D20.2 (A), MX20.2 (ROW)
unnamed: D21.2 (A), MX21.1 (COL)
unnamed: D22.2 (A), MX22.1 (COL)
unnamed: D23.2 (A), MX23.1 (COL)
unnamed: D24.2 (A), MX24.2 (ROW)
unnamed: D25.2 (A), MX25.1 (COL)
unnamed: D26.2 (A), MX26.2 (ROW)
unnamed: D27.2 (A), MX27.1 (COL)
unnamed: D28.2 (A), MX28.1 (COL)
unnamed: D29.2 (A), MX29.2 (ROW)
unnamed: D30.2 (A), MX30.1 (COL)
unnamed: D31.2 (A), MX31.2 (ROW)
unnamed: D32.2 (A), MX32.1 (COL)
unnamed: D33.2 (A), MX33.2 (ROW)
unnamed: D34.2 (A), MX34.1 (COL)
unnamed: D35.2 (A), MX35.2 (ROW)
unnamed: D36.2 (A), MX36.2 (ROW)
unnamed: D37.2 (A), MX37.2 (ROW)
unnamed: D38.2 (A), MX38.1 (COL)
unnamed: D39.2 (A), MX39.2 (ROW)
unnamed: D40.2 (A), MX40.1 (COL)
unnamed: D41.2 (A), MX41.2 (ROW)
unnamed: D42.2 (A), MX42.2 (ROW)
unnamed: D43.2 (A), MX43.2 (ROW)
unnamed: D44.2 (A), MX44.2 (ROW)
unnamed: D45.2 (A), MX45.2 (ROW)
unnamed: D46.2 (A), MX46.2 (ROW)
unnamed: D47.2 (A), MX47.2 (ROW)
unnamed: D48.2 (A), MX48.2 (ROW)
unnamed: D49.2 (A), MX49.2 (ROW)
unnamed: D50.2 (A), MX50.2 (ROW)
unnamed: D51.2 (A), MX51.2 (ROW)
unnamed: D52.2 (A), MX52.2 (ROW)
unnamed: D53.2 (A), MX53.2 (ROW)
unnamed: J1.A5 (CC1), R1.2
unnamed: J1.B5 (CC2), R2.2
unnamed: R3.1, R4.2
unnamed: R5.2, SWR1.2 (B)
unnamed: R7.1, U4.46 (USB_DM)
unnamed: R8.1, U4.47 (USB_DP)
QSPI_CLK: U3.6 (CLK), U4.52 (QSPI_SCLK)
QSPI_D0: U3.5 (DI(IO0)), U4.53 (QSPI_SD0)
QSPI_D1: U3.2 (DO(IO1)), U4.55 (QSPI_SD1)
QSPI_D2: U3.3 (IO2), U4.54 (QSPI_SD2)
QSPI_D3: U3.7 (IO3), U4.51 (QSPI_SD3)
QSPI_SS: R4.1, R5.1, U3.1 (~CS), U4.56 (QSPI_SS_N)
RGB: LED1.3 (DIN), U4.12 (GPIO9)
ROW0: D1.1 (K), D2.1 (K), D3.1 (K), D4.1 (K), D5.1 (K), D6.1 (K), D7.1 (K), U4.3 (GPIO1)
ROW1: D15.1 (K), D16.1 (K), D17.1 (K), D18.1 (K), D19.1 (K), D20.1 (K), D21.1 (K), U4.31 (GPIO20)
ROW2: D29.1 (K), D30.1 (K), D31.1 (K), D32.1 (K), D33.1 (K), D34.1 (K), D35.1 (K), U4.35 (GPIO23)
ROW3: D42.1 (K), D43.1 (K), D44.1 (K), D45.1 (K), D46.1 (K), U4.30 (GPIO19)
ROW4: D8.1 (K), D9.1 (K), D10.1 (K), D11.1 (K), D12.1 (K), D13.1 (K), D14.1 (K), U4.4 (GPIO2)
ROW5: D22.1 (K), D23.1 (K), D24.1 (K), D25.1 (K), D26.1 (K), D27.1 (K), D28.1 (K), U4.5 (GPIO3)
ROW6: D36.1 (K), D37.1 (K), D38.1 (K), D39.1 (K), D40.1 (K), D41.1 (K), U4.6 (GPIO4)
ROW7: D47.1 (K), D48.1 (K), D49.1 (K), D50.1 (K), D51.1 (K), D52.1 (K), D53.1 (K), U4.13 (GPIO10)
RUN: R6.2, SWR2.2 (B), U4.26 (RUN)
SWCLK: U4.24 (SWCLK)
SWDIO: U4.25 (SWDIO)
VCC: F1.1, J1.A4 (VBUS), J1.A9 (VBUS), J1.B4 (VBUS), J1.B9 (VBUS), U2.5 (VP)
XIN: C13.1, U4.20 (XIN), Y1.3
XOUT: R9.2, U4.21 (XOUT)

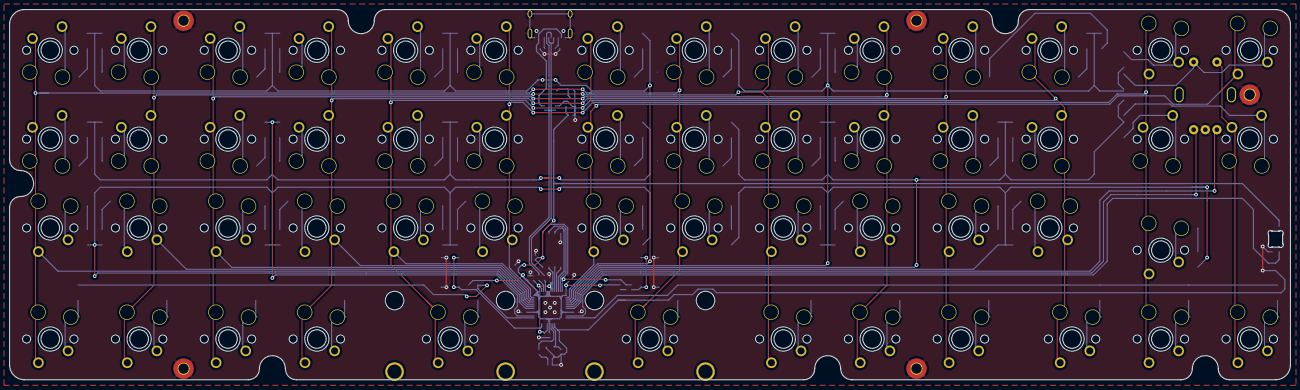
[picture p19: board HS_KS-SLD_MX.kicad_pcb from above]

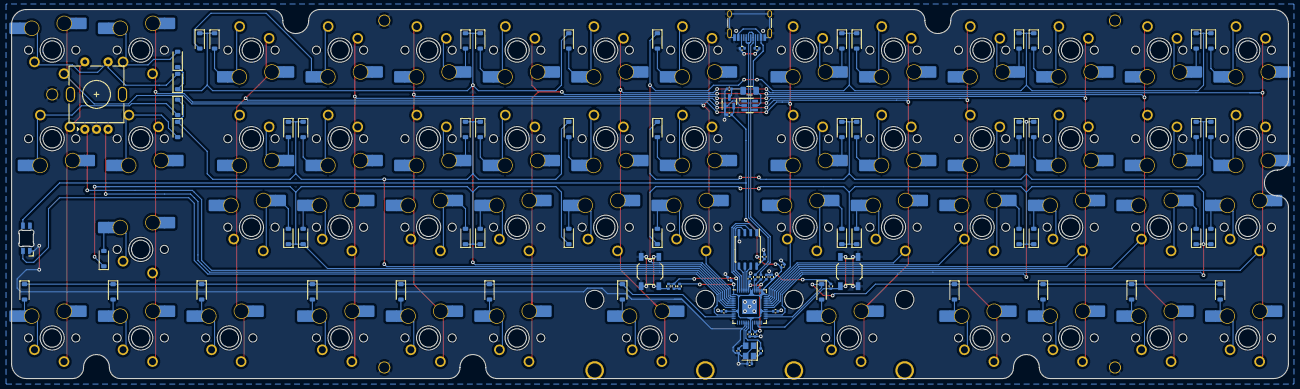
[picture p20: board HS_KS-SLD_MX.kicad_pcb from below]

Board: 2 copper layers, 274.6 x 79.4 mm, 147 parts (89 on the bottom side), 94 nets.

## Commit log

2023-08-02 Initial commit of PCB source, unfinished
    [fourtyeighty.kicad_pcb, fourtyeighty.kicad_sch]
2023-08-03 routed rows
    [fourtyeighty.kicad_pcb]
2023-08-03 A bit more routing
    [fourtyeighty.kicad_pcb]
2023-08-03 almost done with columns
    [fourtyeighty.kicad_pcb, fourtyeighty.kicad_sch]
2023-08-03 Just a few more connections
    [fourtyeighty.kicad_pcb, fourtyeighty.kicad_sch]
2023-08-04 Completed MX PCB
    [fourtyeighty.kicad_pcb, fourtyeighty.kicad_sch]
2023-08-06 Add GLP_PCB, name fix
    [GLP_PCB.kicad_pcb, GLP_PCB.kicad_sch, LowProTest.kicad_pcb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]
2023-08-23 lo-pro test production
    [LowProTest.kicad_pcb, bom.csv, designators.csv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]
2023-10-31 add mx+gs hotswap PCB
    [HS_KS-SLD_MX.kicad_pcb, HS_KS-SLD_MX.kicad_sch]
2023-11-02 Routed, will DRC tomorrow
    [HS_KS-SLD_MX.kicad_pcb, HS_KS-SLD_MX.kicad_sch]
2023-11-03 remove unneeded PCB options
    [GLP_PCB.kicad_pcb, GLP_PCB.kicad_sch, MX_PCB.kicad_pcb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]
2023-11-05 add quick image of approximate artwork placement on PCB
2023-11-13 Added WIP graphics to PCB (and dirty Inkscape SVG converted from PDF)
2023-11-20 add PCB prod files, clean up silkscreen
    [bom.csv, designators.csv, positions.csv]
2023-11-20 update bom
    [bom.csv]
2023-11-21 add skeleton case files
    [80forty-plates_to_cut-2023_11_20.dxf, baseplate.kicad_pcb, baseplate.kicad_sch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]
2024-01-13 add images
    [80forty-plates_to_cut-2023_11_20.dxf]
2024-02-05 rename folder for skeleton case files
    [80forty-plates_to_cut-2023_11_20.dxf, baseplate.kicad_pcb, baseplate.kicad_sch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]
2024-02-05 add starter files for acrylic case
